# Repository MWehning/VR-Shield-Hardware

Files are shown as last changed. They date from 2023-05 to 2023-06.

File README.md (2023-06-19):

View full project at:
https://www.openhardware.io/view/33050

## Kicad files required to replicate the VR-Shield PCB. 

# Required components:

* SMD-Resistors (0805)

  * 1x 120 Ohm
  
  * 1x 3.3k Ohm
  
  * 1x 33k Ohm
  
* 1x LED Blue (0805)

* 1x IRF7404 Mosfet (SOIC 8)

* 1x BC847 NPN Transistor (SOT 23)

* 1x ESP32 WROOM32 Devkit C

* 2x 02x08 angled pin header (2.54mm, middle two rows need to be removed to form two 02x03 sockets)

## Build instructions can be found at /bom/ibom.html

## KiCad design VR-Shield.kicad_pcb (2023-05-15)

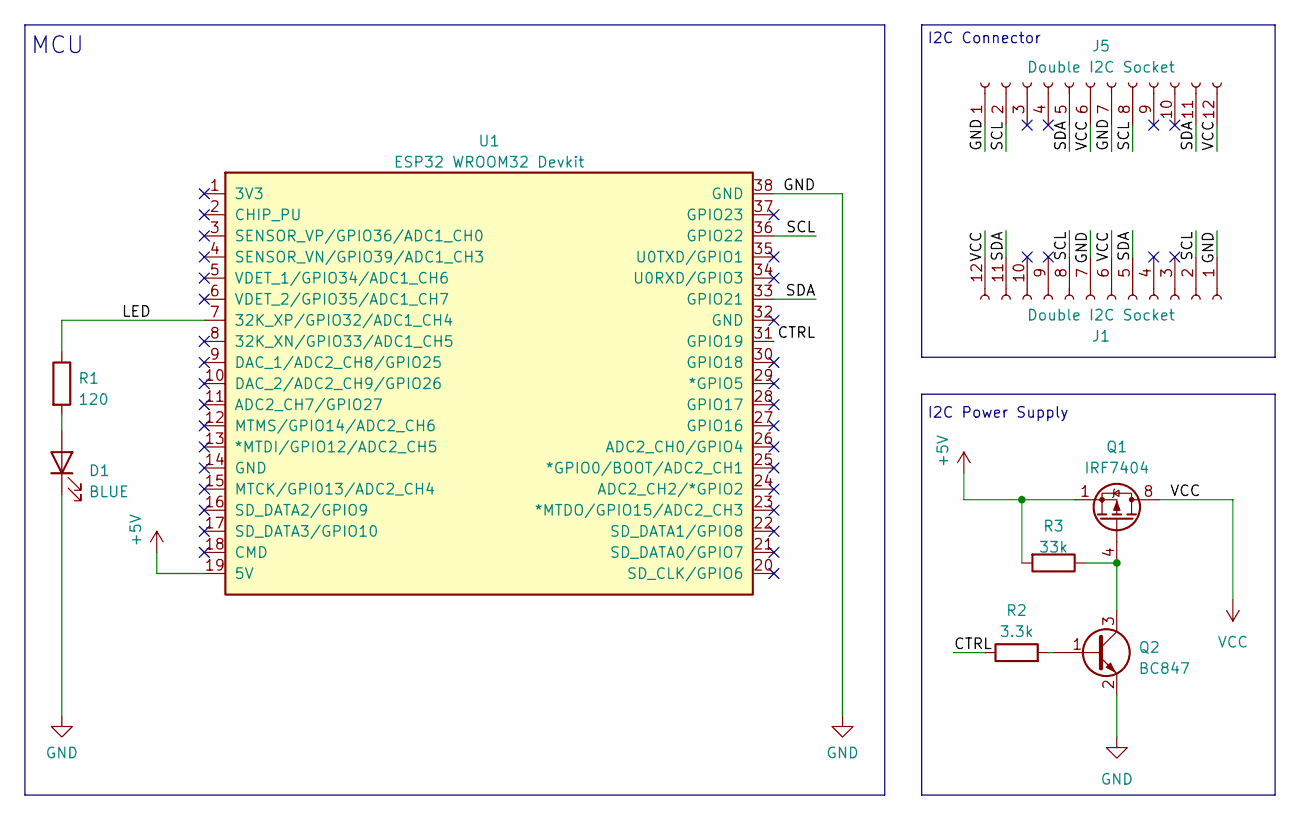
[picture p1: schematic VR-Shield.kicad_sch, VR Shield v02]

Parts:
D1: BLUE; LED_0805_2012Metric_Pad1.15x1.40mm_HandSolder
J1, J5: Double I2C Socket; Custom Socket I2C
Q1: IRF7404; SOIC-8_3.9x4.9mm_P1.27mm
Q2: BC847; SOT-23
R1: 120; R_0805_2012Metric_Pad1.20x1.40mm_HandSolder
R2: 3.3k; R_0805_2012Metric_Pad1.20x1.40mm_HandSolder
R3: 33k; R_0805_2012Metric_Pad1.20x1.40mm_HandSolder
U1: ESP32 WROOM32 Devkit; ESP32-DevKitC

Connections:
/5V: Q1.1 (S), Q1.2 (S), Q1.3 (S), R3.2, U1.19 (5V)
/LED: R1.1, U1.7 (32K_XP/GPIO32/ADC1_CH4)
/SCL: J1.2, J1.8, J5.2, J5.8, U1.36 (GPIO22)
/SDA: J1.5, J1.11, J5.5, J5.11, U1.33 (GPIO21)
/VCC: J1.6, J1.12, J5.6, J5.12, Q1.5 (D), Q1.6 (D), Q1.7 (D), Q1.8 (D)
GND: D1.1 (K), J1.1, J1.7, J5.1, J5.7, Q2.2 (E), U1.38 (GND)
unnamed: D1.2 (A), R1.2
unnamed: Q1.4 (G), Q2.3 (C), R3.1
unnamed: Q2.1 (B), R2.2
unnamed: R2.1, U1.31 (GPIO19)

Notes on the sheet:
I2C Power Supply
I2C Connector
MCU

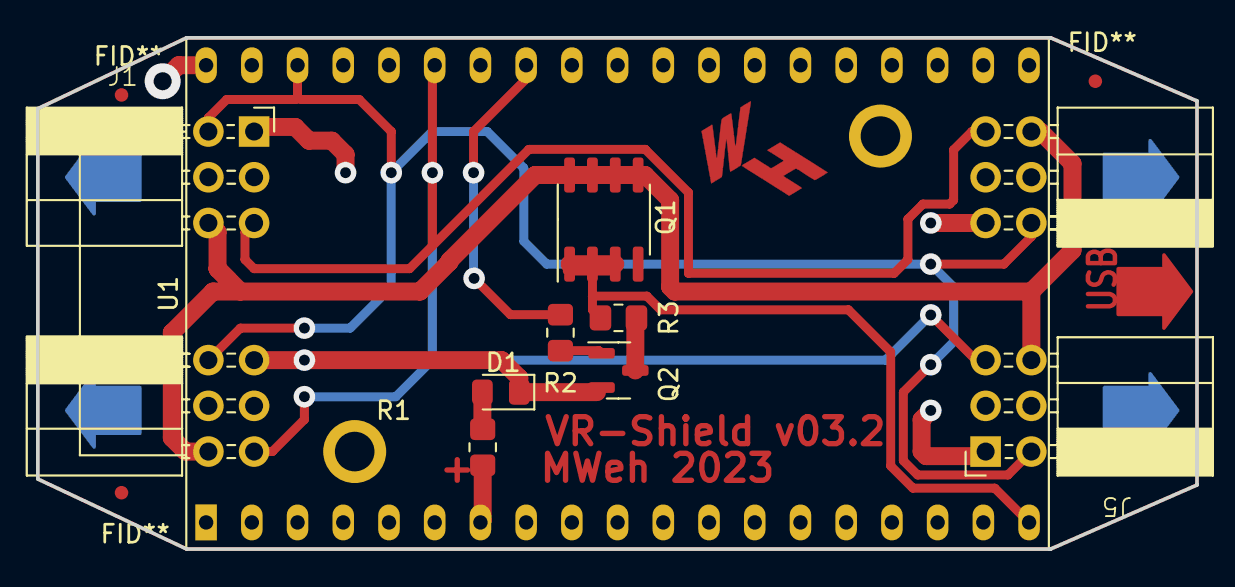
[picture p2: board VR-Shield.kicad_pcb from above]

Board: 2 copper layers, 64.4 x 28.4 mm, 12 parts (0 on the bottom side), 10 nets.

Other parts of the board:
FID**: Fiducial_0.75mm_Mask1.5mm
FID**#2, FID**#3: Fiducial_0.75mm_Mask1.5mm

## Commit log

2023-03-07 Fixed issues with pad size and distance Please enter the commit message for your changes. Lines starting
    [VR-Shield.kicad_pcb, VR-Shield.kicad_sch]
2023-04-17 t V03!!!!
    [VR-Shield-B_Cu.gbr, VR-Shield-B_Cu_UV.gbr, VR-Shield-Eco1_User.gbr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]
2023-05-15 User friendlyness improved
    [VR-Shield.kicad_pcb, VR-Shield.kicad_sch]

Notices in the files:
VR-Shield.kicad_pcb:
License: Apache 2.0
